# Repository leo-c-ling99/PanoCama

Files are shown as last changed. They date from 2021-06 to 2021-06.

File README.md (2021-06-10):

# PanoCama
Have you ever want to take a panoramic photo, automatically? The PanoCama is a low-cost device for taking wide-angle photographs. With its dual-cameras, it's able to roughly measure depth for fast environmental mapping.

This camera system was made with the mini-pan tilt system from Adafruit, an ESP32 DEVKIT, and two ArduCAM 2MP cameras. Image stitching and stereo vision components are performed using the OpenCV library for Python.

Project for EE 327: Electronic System Design II.

## Organization
The code I developed over the course is ordered here into Firmware, Image Processing, and Web sections. This project is organized as multiple proof of concepts for the various sections rather than one project with all components nicely interfaced together. Firmware is primarily C/C++ code developed for an ESP32 DEVKIT V1 for the Arduino Environment developed using PlatformIO. Image Processing is primarily Python code exploring the OpenCV library. Web is mostly setup code for an Tornado server with WebSockets and a webpage interface. PCB contains the two boards designed for this project. 

As of now, to interface the ESP32 with the Tornado Webserver, the address of the server and the local WiFi password must be changed within the main.cpp file.

3D mount: https://cad.onshape.com/documents/40f7b32b21ebe9fb9dda074d/w/69e21c5f167fa995fddc0409/e/9e02c831b684e933273a17e4

### Copyright © 2021 Leo Ling

Permission is hereby granted, free of charge, to any person obtaining a copy of this software and associated documentation files (the “Software”), to deal in the Software without restriction, including without limitation the rights to use, copy, modify, merge, publish, distribute, sublicense, and/or sell copies of the Software, and to permit persons to whom the Software is furnished to do so, subject to the following conditions:

The above copyright notice and this permission notice shall be included in all copies or substantial portions of the Software.

THE SOFTWARE IS PROVIDED “AS IS”, WITHOUT WARRANTY OF ANY KIND, EXPRESS OR IMPLIED, INCLUDING BUT NOT LIMITED TO THE WARRANTIES OF MERCHANTABILITY, FITNESS FOR A PARTICULAR PURPOSE AND NONINFRINGEMENT. IN NO EVENT SHALL THE AUTHORS OR COPYRIGHT HOLDERS BE LIABLE FOR ANY CLAIM, DAMAGES OR OTHER LIABILITY, WHETHER IN AN ACTION OF CONTRACT, TORT OR OTHERWISE, ARISING FROM, OUT OF OR IN CONNECTION WITH THE SOFTWARE OR THE USE OR OTHER DEALINGS IN THE SOFTWARE.

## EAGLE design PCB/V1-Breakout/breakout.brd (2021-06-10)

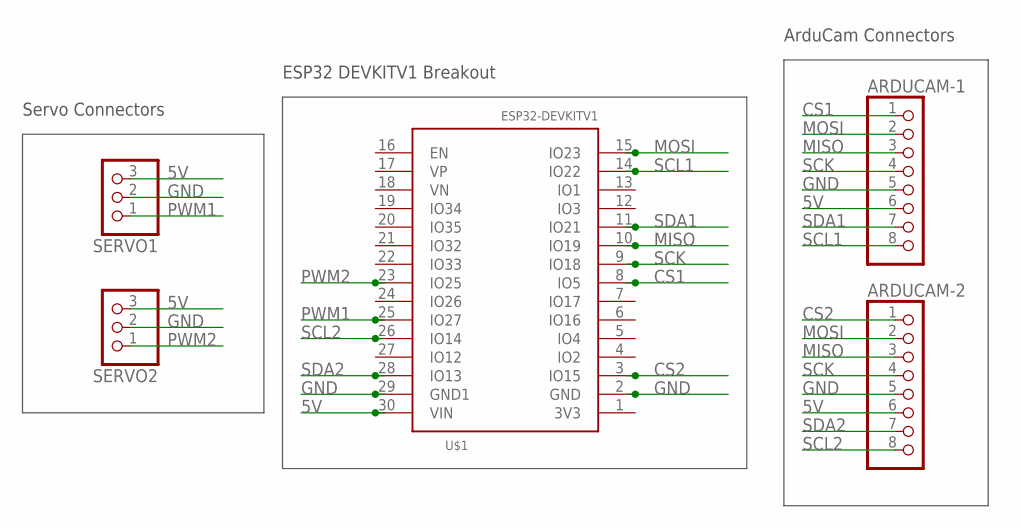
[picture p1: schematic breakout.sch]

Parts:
ARDUCAM-1, ARDUCAM-2: PINHD-1X8BIG; 1X08-BIG
SERVO1, SERVO2: PINHD-1X3; 1X03
U$1: ESP32DEVKITV1; ESP32-DEVKITV1

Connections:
5V: ARDUCAM-1.6, ARDUCAM-2.6, SERVO1.3, SERVO2.3, U$1.30 (VIN)
CS1: ARDUCAM-1.1, U$1.8 (IO5)
CS2: ARDUCAM-2.1, U$1.3 (IO15)
GND: ARDUCAM-1.5, ARDUCAM-2.5, SERVO1.2, SERVO2.2, U$1.2 (GND), U$1.29 (GND1)
MISO: ARDUCAM-1.3, ARDUCAM-2.3, U$1.10 (IO19)
MOSI: ARDUCAM-1.2, ARDUCAM-2.2, U$1.15 (IO23)
PWM1: SERVO1.1, U$1.25 (IO27)
PWM2: SERVO2.1, U$1.23 (IO25)
SCK: ARDUCAM-1.4, ARDUCAM-2.4, U$1.9 (IO18)
SCL1: ARDUCAM-1.8, U$1.14 (IO22)
SCL2: ARDUCAM-2.8, U$1.26 (IO14)
SDA1: ARDUCAM-1.7, U$1.11 (IO21)
SDA2: ARDUCAM-2.7, U$1.28 (IO13)

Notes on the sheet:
Servo Connectors
ESP32 DEVKITV1 Breakout
ArduCam Connectors

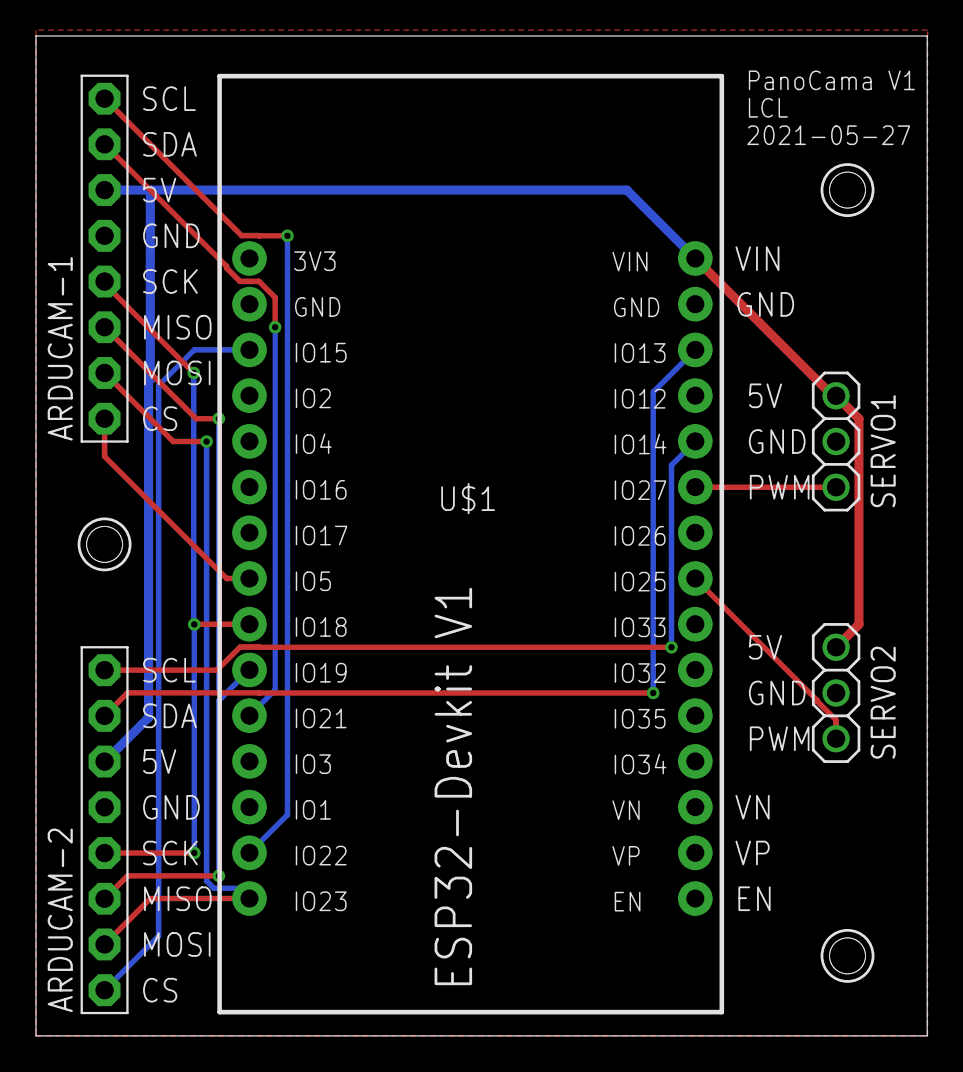
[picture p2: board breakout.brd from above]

Board: 2 copper layers, 49.5 x 55.5 mm, 5 parts (0 on the bottom side), 13 nets.

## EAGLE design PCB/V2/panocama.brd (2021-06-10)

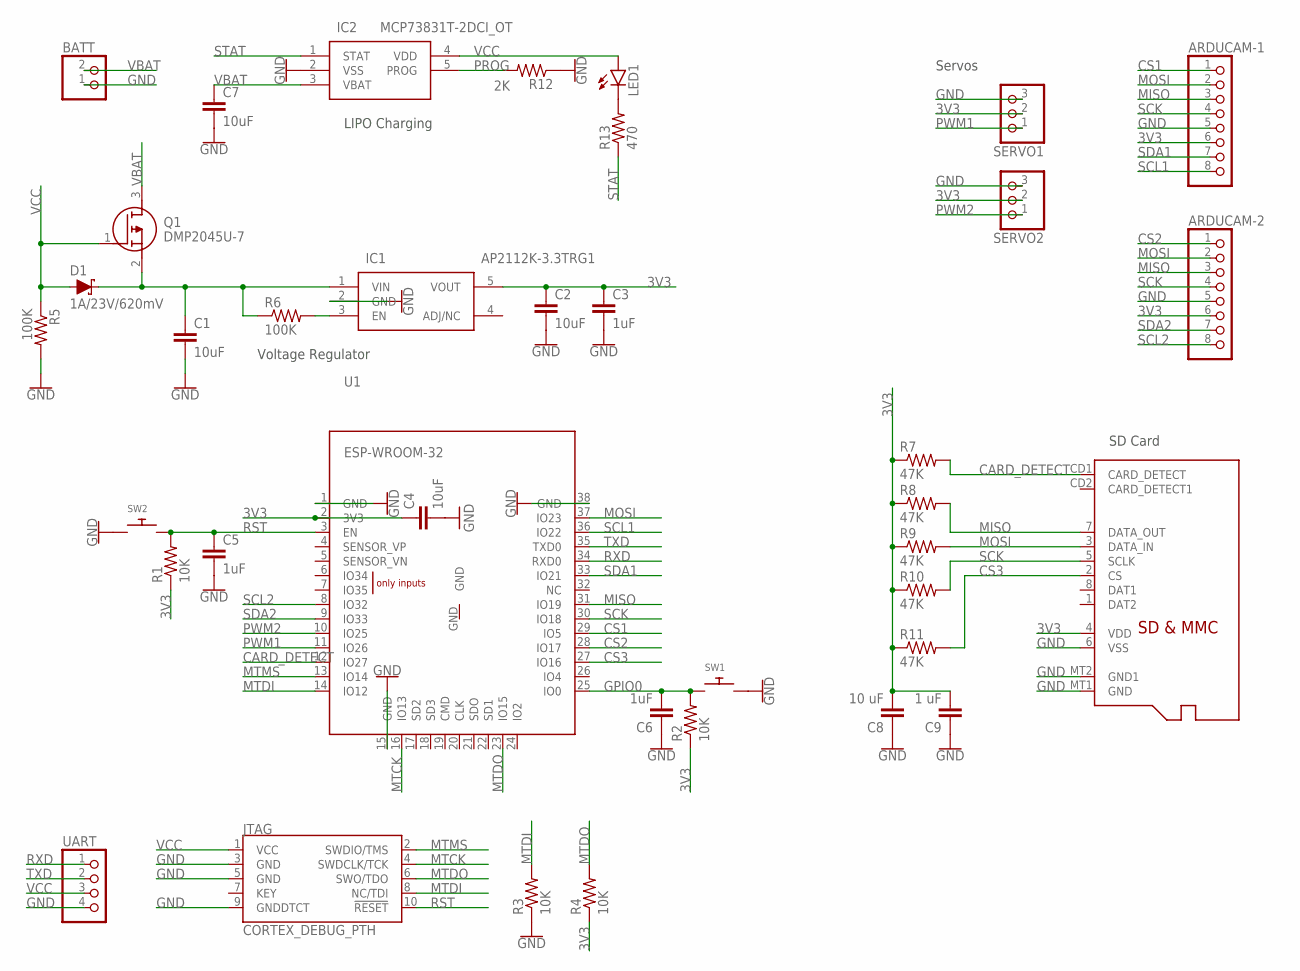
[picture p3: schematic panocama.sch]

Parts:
ARDUCAM-1, ARDUCAM-2: PINHD-1X8CLEANBIG; 1X08-CLEANBIG
BATT: JST_2PIN-SMT; JST-PH-2-SMT
C1, C2, C4, C7: 10uF; 0805
C3, C5, C6: 1uF; 0805
C8: 10 uF; 0805
C9: 1 uF; 0805
D1: 1A/23V/620mV; SOD-323
IC1: AP2112K-3.3TRG1; SOT95P282X130-5N
IC2: MCP73831T-2DCI_OT; SOT95P270X145-5N
JTAG: CORTEX_DEBUG_PTH; 2X5-PTH-1.27MM
LED1: LED0603; LED-0603
Q1: DMP2045U-7; SOT96P240X110-3N
R1, R2, R3, R4: 10K; 0805
R5, R6: 100K; 0805
R7, R8, R9, R10, R11: 47K; 0805
R12: 2K; 0805
R13: 470; 0805
SD: MICROSD
SERVO1, SERVO2: PINHD-1X3; 1X03
SW1, SW2: SWITCH_PUSHBUTTONSOFTTOUCHSMD_SJ; PUSHBUTTON_SMD_SJ
U1: ESP-WROOM-32
UART: PINHD-1X4; 1X04

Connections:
3V3: ARDUCAM-1.6, ARDUCAM-2.6, C2.1, C3.1, C4.1, C8.2, C9.2, IC1.5 (VOUT), R1.1, R2.1, R4.1, R7.1, R8.1, R9.1, R10.1, R11.1, SD.4 (VDD), SERVO1.2, SERVO2.2, U1.2 (3V3)
CARD_DETECT: R7.2, SD.CD1 (CARD_DETECT), U1.12 (IO27)
CS1: ARDUCAM-1.1, U1.29 (IO5)
CS2: ARDUCAM-2.1, U1.28 (IO17)
CS3: R11.2, SD.2 (CS), U1.27 (IO16)
GND: ARDUCAM-1.5, ARDUCAM-2.5, BATT.1 (2), C1.2, C2.2, C3.2, C4.2, C5.2, C6.1, C7.2, C8.1, C9.1, IC1.2 (GND), IC2.2 (VSS), JTAG.3 (GND), JTAG.5 (GND), JTAG.9 (GNDDTCT), R3.1, R5.2, R12.1, SD.6 (VSS), SD.MT1 (GND), SD.MT2 (GND1), SERVO1.3, SERVO2.3, SW1.P$2, SW2.P$1, U1.1 (GND), U1.15 (GND), U1.38 (GND), UART.4
GPIO0: C6.2, R2.2, SW1.P$1, U1.25 (IO0)
MISO: ARDUCAM-1.3, ARDUCAM-2.3, R8.2, SD.7 (DATA_OUT), U1.31 (IO19)
MOSI: ARDUCAM-1.2, ARDUCAM-2.2, R9.2, SD.3 (DATA_IN), U1.37 (IO23)
MTCK: JTAG.4 (SWDCLK/TCK), U1.16 (IO13)
MTDI: JTAG.8 (NC/TDI), R3.2, U1.14 (IO12)
MTDO: JTAG.6 (SWO/TDO), R4.2, U1.23 (IO15)
MTMS: JTAG.2 (SWDIO/TMS), U1.13 (IO14)
unnamed: IC1.3 (EN), R6.2
unnamed: C1.1, D1.C, IC1.1 (VIN), Q1.2 (S), R6.1
unnamed: LED1.C, R13.2
PROG: IC2.5 (PROG), R12.2
PWM1: SERVO1.1, U1.11 (IO26)
PWM2: SERVO2.1, U1.10 (IO25)
RST: C5.1, JTAG.10 (!RESET), R1.2, SW2.P$2, U1.3 (EN)
RXD: U1.34 (RXD0), UART.1
SCK: ARDUCAM-1.4, ARDUCAM-2.4, R10.2, SD.5 (SCLK), U1.30 (IO18)
SCL1: ARDUCAM-1.8, U1.36 (IO22)
SCL2: ARDUCAM-2.8, U1.8 (IO32)
SDA1: ARDUCAM-1.7, U1.33 (IO21)
SDA2: ARDUCAM-2.7, U1.9 (IO33)
STAT: IC2.1 (STAT), R13.1
TXD: U1.35 (TXD0), UART.2
VBAT: BATT.2 (1), C7.1, IC2.3 (VBAT), Q1.3 (D)
VCC: D1.A, IC2.4 (VDD), JTAG.1 (VCC), LED1.A, Q1.1 (G), R5.1, UART.3

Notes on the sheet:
LIPO Charging
Voltage Regulator
SD Card
Servos

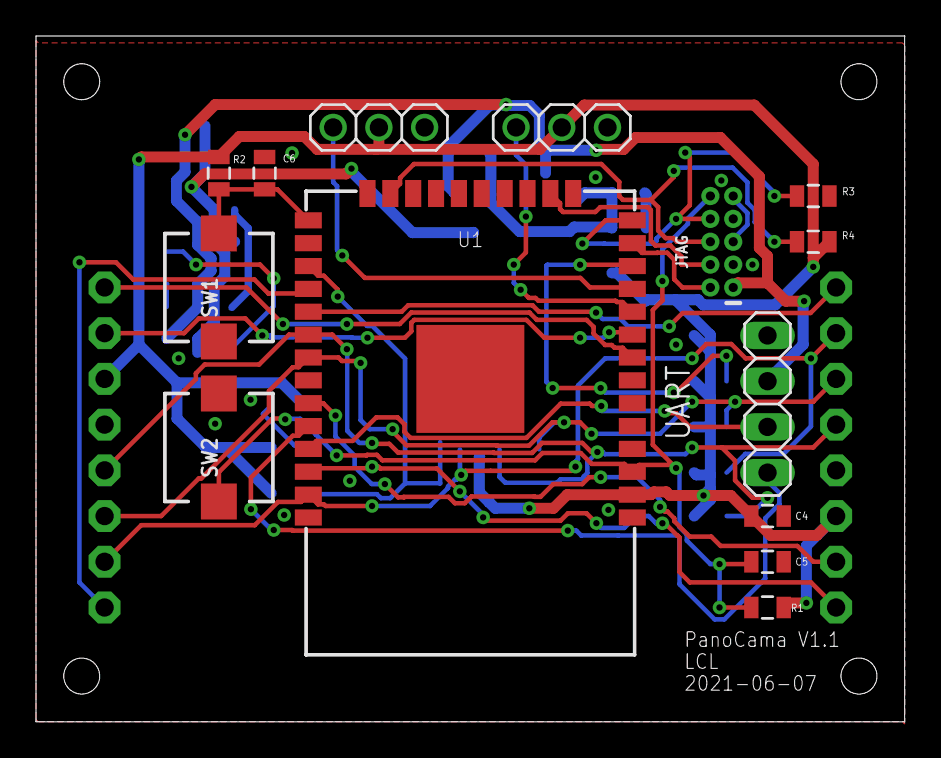
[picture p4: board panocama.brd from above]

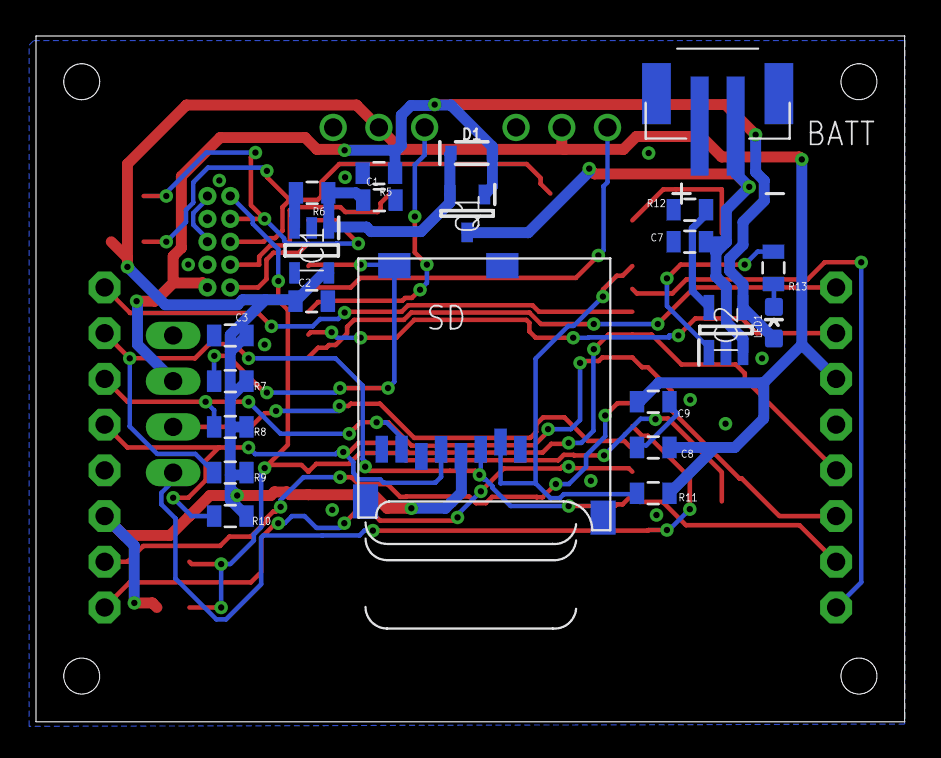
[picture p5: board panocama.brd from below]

Board: 2 copper layers, 48.3 x 38.1 mm, 38 parts (22 on the bottom side), 30 nets.

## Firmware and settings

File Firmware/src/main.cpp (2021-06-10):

#include <Arduino.h>
#include <camera_wrapper.h>
#include <servos_wrapper.h>
#include <ws_wrapper.h>
#include "config.h"

// Flags set by WebSocket
//extern struct ws_received_cmd received_flags;

void take_send_single(ArduCAM& cam) {
	start_capture(cam);
  	Serial.println("CAM Capturing");


	int total_time = 0;

	total_time = millis();
	while (!cam.get_bit(ARDUCHIP_TRIG, CAP_DONE_MASK));
	total_time = millis() - total_time;
	Serial.print("capture total_time used (in miliseconds):");
	Serial.println(total_time, DEC);

	total_time = 0;
  
  	Serial.println("CAM Capture Done!");
  	total_time = millis();

	size_t len = start_picture_read(cam);
	Serial.println(len);
	size_t payload_len;
	// Start send
	while (len > 0) {
		Serial.println(len);
		payload_len = len - fill_picture_buffer(cam, len);
		len -= payload_len;
		// Wait until message has been sent
		while (!webSocket.sendBIN(image_buffer, payload_len)) {
			Serial.println("Send Failed");
			delay(500);
		}
	}
	// Sent text to acknowledge that message has been fully sent
	while (!webSocket.sendTXT("Pic Complete")) {
			delay(1000);
	}

	total_time = millis() - total_time;
  Serial.print("send total_time used (in miliseconds):");
  Serial.println(total_time, DEC);
  Serial.println("CAM send Done!");
}

void take_send_pano() {
	for (int pan_pos = SERVO_MIN; pan_pos < SERVO_MAX; pan_pos += 3) {
		Serial.println(pan_pos);
		servo_move(PWN_CHANNEL_PAN, pan_pos);
		delay(1000);
		take_send_single(cam1);
		take_send_single(cam2);
	}

	Serial.println("Pano Complete");
}

void setup() {
	Serial.begin(115200);
	// Setup WiFi and WebSockets
	wifi_connect();
	init_ws();
	// Setup Cameras
	init_cameras();
	// Setup Servos
	servo_setup();
}

void loop() {
	webSocket.loop();

	if (!received_flags.stop_flag && received_flags.num_received > 0) {
		Serial.println("Flags Set");

		// Check if any move servos flags set
		if (received_flags.move_servo_pan) {
			servo_move(PWN_CHANNEL_PAN, received_flags.servo_pan_ds);

			// Remove Flags
			received_flags.move_servo_pan = false;
			received_flags.servo_pan_ds = 0;
			received_flags.num_received -= 1;
			delay(1000);
		} 
		if (received_flags.move_servo_tilt) {
			servo_move(PWM_CHANNEL_TILT, received_flags.servo_tilt_ds);

			// Remove Flags
			received_flags.move_servo_tilt = false;
			received_flags.servo_tilt_ds = 0;
			received_flags.num_received -= 1;
			delay(1000);
		}

		// Check for take single picture command
		if (received_flags.capture_single_pic) {
			if (received_flags.capture_single_pic_cam == 1) {
				take_send_single(cam1);
			} else {
				take_send_single(cam2);
			}
			
			received_flags.capture_single_pic = false;
			received_flags.capture_single_pic_cam = false;
			received_flags.num_received -= 1;
			delay(1000);
		}

		// Check for take Panoramic
		if (received_flags.capture_pano) {
			take_send_pano();
			received_flags.capture_pano = false;
			received_flags.capture_pano_cam = false;
			received_flags.num_received -= 1;
			delay(1000);
		}
	} 
}

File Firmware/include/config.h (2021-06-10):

// WiFi setup
/*#define WIFI_SSID "The Hare"
#define WIFI_PASS "Parsley?nSage?nRosemary?yThyme?y"
#define SERVER_URL "192.168.0.15"
#define SERVER_PORT 8888
#define UPLOAD_EXT "websocket" */

// Camera Pins
/*
#define CAMERA_1_SCK    14
#define CAMERA_1_MISO   12
#define CAMERA_1_MOSI   13
#define CAMERA_1_CS     26
#define CAMERA_2_SCK    18
#define CAMERA_2_MISO   19
#define CAMERA_2_MOSI   23
#define CAMERA_2_SCK    14
#define CAMERA_2_MISO   12
#define CAMERA_2_MOSI   13
#define CAMERA_2_CS     5

#define SPI_FREQUENCY   4000000
*/

// Servos
/*
#define SERVO_PAN_PIN       2
#define SERVO_TILT_PIN      4
#define SERVO_MIN   5
#define SERVO_MAX   33 */

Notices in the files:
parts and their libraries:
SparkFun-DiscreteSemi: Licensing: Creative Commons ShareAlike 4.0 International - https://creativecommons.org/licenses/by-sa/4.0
